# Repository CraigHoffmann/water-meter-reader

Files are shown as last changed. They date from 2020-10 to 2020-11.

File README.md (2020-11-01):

# Water Meter Reader
## Remote reading of a South Australian mains water meter

I made this water meter reader specifically for use with my home assistant monitoring system.  (If you haven't heard of [home assistant](https://www.home-assistant.io/) I suggest you check it out!).  I have created a discussion thread on the home ssistant [forum here](https://community.home-assistant.io/t/whole-of-house-water-meter-reader-south-australian-meter/240961).  After already designing a successful electricity meter reader this was my next requirement for home monitoring and automation.
I have read that some water meters have a rotating magnet inside the meter that can be detected by a hall effect sensor but couldn't find any specific information about the meter at my house (a typical South Australian mains water meter) so I decided to sense the rotating needle on the main dial.

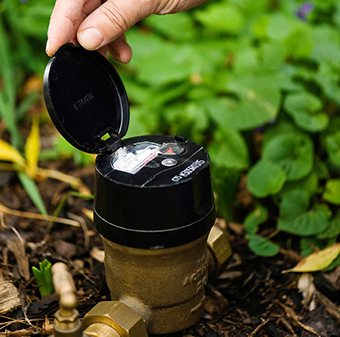
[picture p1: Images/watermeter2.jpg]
SA Water Meter
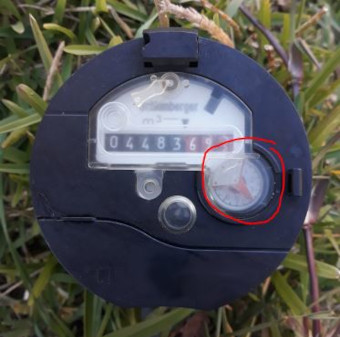
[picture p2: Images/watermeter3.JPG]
Meter Dial
 

This is what it looks like with the sensor fitted...

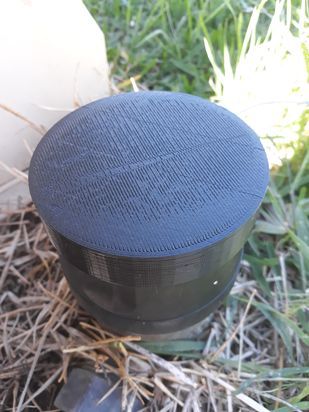
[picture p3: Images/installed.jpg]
Installed


## Electronics

The meter reader uses a [WeMOS D1 Mini (R3)](https://docs.wemos.cc/en/latest/d1/d1_mini.html) but would work with any ESP8266 with a few conditions.

* It uses the ADC Input for the sensor reading so a variant that has access to that pin is required.  If the module doesn't have a resistor voltage divider on the ADC input you will need to add it/adjust the resistors to the sensor.
* The WeMOS has a built in 3.3v regulator for the ESP8266 and the sensor runs at 5V so suitable supply electronics are required.

An optical reflectance sensor (TCRT5000) is used to detect the IR reflected light and is monitored using the analog input.  As the dial turns the reflectance changes as the needle passes by.  Trigger levels are set on the analog signal to count the revolutions of the dial.  Its simple but works reliably for my meter.

I have the Wemos D1 in the garage and run a 3wire cable out to the meter with for the sensor.  Alternatively all electrics could be placed at the meter and run power to the meter (or maybe use solar and batteries?)

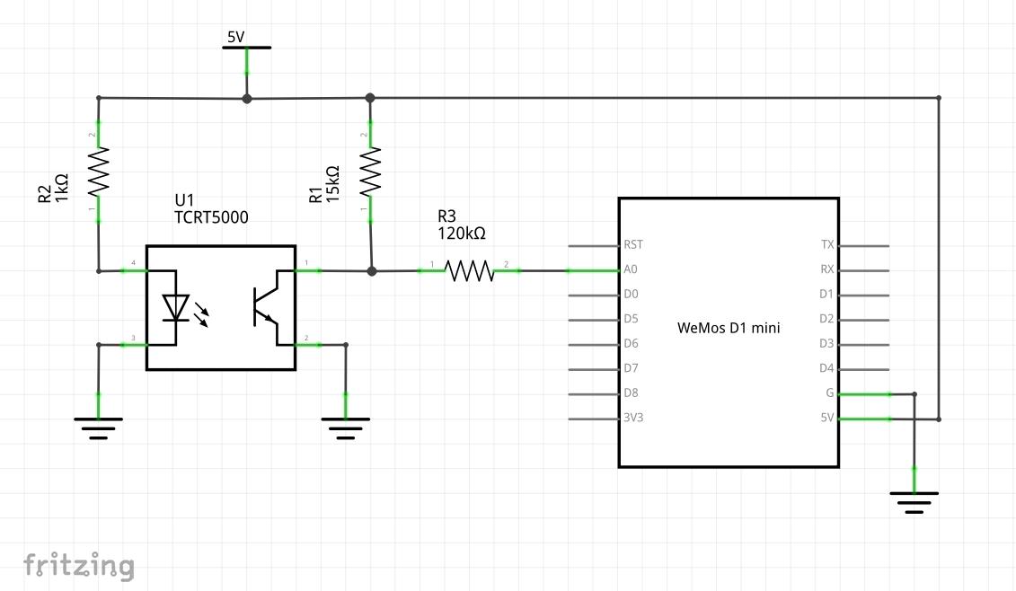
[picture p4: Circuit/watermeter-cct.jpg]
Circuit
|  |
:-------------------------:

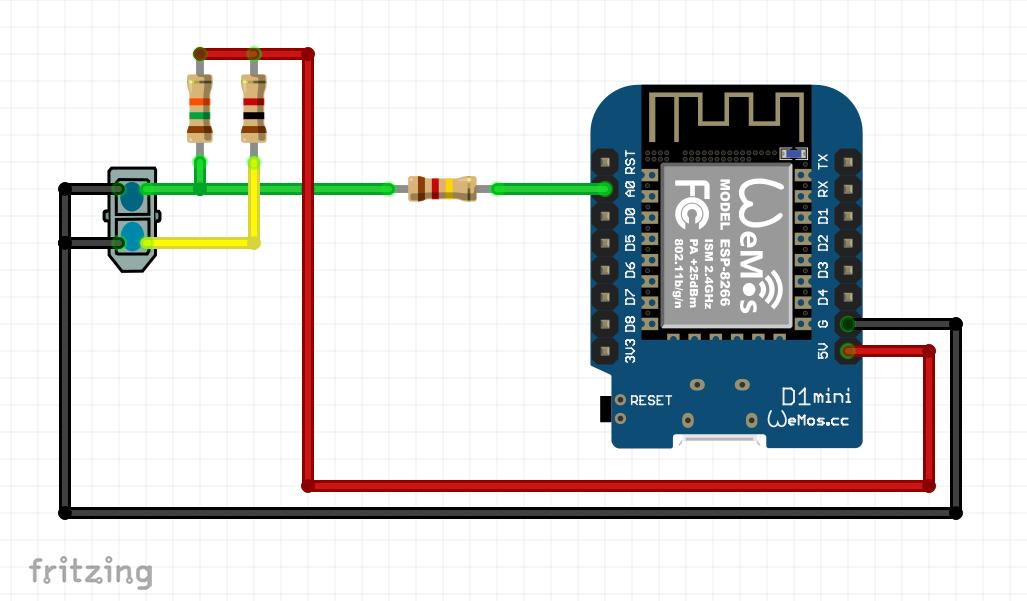
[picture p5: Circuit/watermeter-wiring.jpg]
Wiring
|  |
:-------------------------:

## Firmware

The Arduino IDE was used to develop and program the code.  If you have used this before with the ESP8266 devices you should have no problems.  If you're new to arduino or ESP8266's then there are hundreds of pages on the internet detailing how to setup the environment and program devices - I suggest you start by looking for one that suits your level of background knowledge to get up to speed.

Simply compile and upload the **WaterMeter.ino** code using the Arduino IDE.

## Case

My water meter cover had been broken off for years so I decided to make a new 3D printed cover that doubled as the case for the sensor.  The lid is "keyed" with the old lid hinge mounting so that the sensor is always aligned to the rotating dial. Files are available in the github repository to download and print your own. The electronics are just hot glued to the inside plate. 

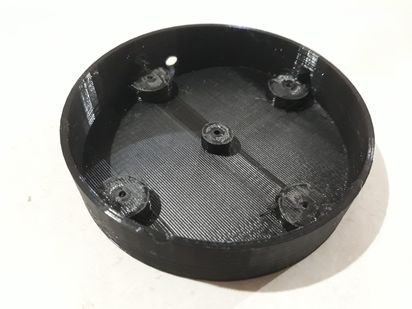
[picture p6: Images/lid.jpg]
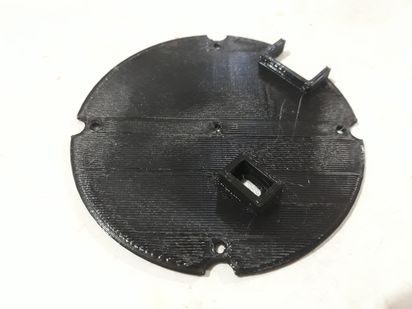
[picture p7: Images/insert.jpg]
 

If you don't have access to a 3D printer you could probably use the bottom of a plastic container or tin - anything that fits snug over the meter to keep the sensor aligned to the dial.  Use your imagination and maker skills.

## Setup

First step is to **configure the wifi** to connect to your network.  If the device wifi has not been setup previously WiFiManager will automatically setup an access point called **watermeter**. Connect to the access point with password **wifisetup** and then load the default page 192.168.4.1 and enter your network wifi details.   **If you want to force the erasure of the wifi settings for some reason power up the device with pin D7 (GPIO13) pulled to ground.**  This will erase the wifi settings and go stright to the WiFiManager access point config.

After entering your wifi details in wifimanager restart the Wemos D1 mini and wifimanager should connect to your network.  

If you have a serial monitor plugged in when powering up the device it will display the assigned IP address on startup.  If you don't have an easy way of finding device IP addresses on your network then I suggest allocating an IP address in your router.  

* The main water meter setup page can be found at http://\<device-ip\>/  
* Alternatively if your system supports multicast DNS then you can use http://watermeter.local/ 

The default landing page is shows the cumulative count of kLiters used as well as the usage in the past 1 minute.  Both the MQTT setup and Sensor setup can be accessed from the home page. 

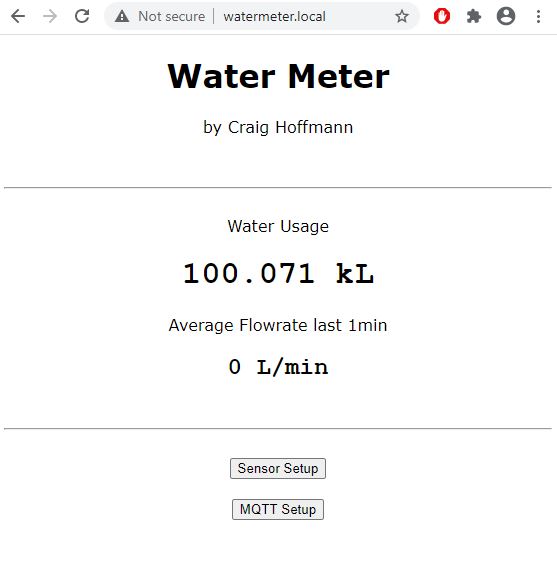
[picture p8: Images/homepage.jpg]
Homepage
|  |
:-------------------------:

### Setup the MQTT connection.

This is done by either clicking on the **MQTT Setup** button from the home page or entering the url directly http://watermeter.local/mqttsetup - replace watermeter.local with the ip address if you don't have mDNS available.

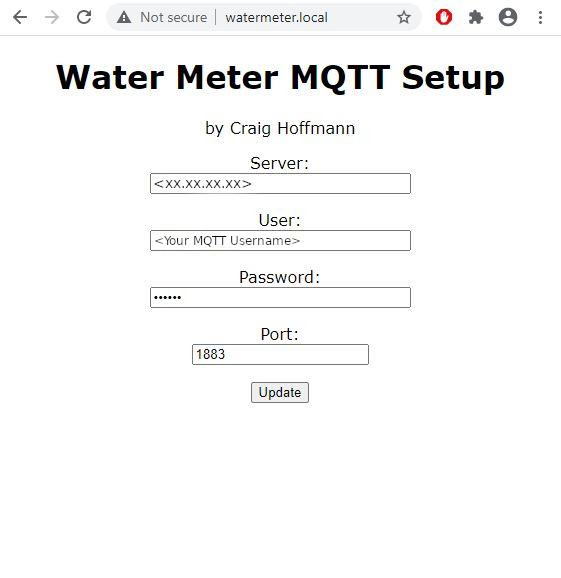
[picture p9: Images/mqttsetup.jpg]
MQTT Setup
|  | 
:-------------------------:

### Setup the sensor trigger thresholds

To access the sensor setup page in a browser click on the **Sensor Setup** button on the water meter home page or alternatively enter http://watermeter.local/sensorsetup in the browser address bar

It is necessary to setup the **trigger thresholds** for the sensor for the counter to work properly.  The best way to do this is to turn on a water tap full so you get a resonableflow rate then refresh the sensor setup page.  You should see the sensor signal rise and fall as the meter dial rotates as shown below.  Set the thresholds a bit below the maximum and a bit above the minimum as can be seen below.

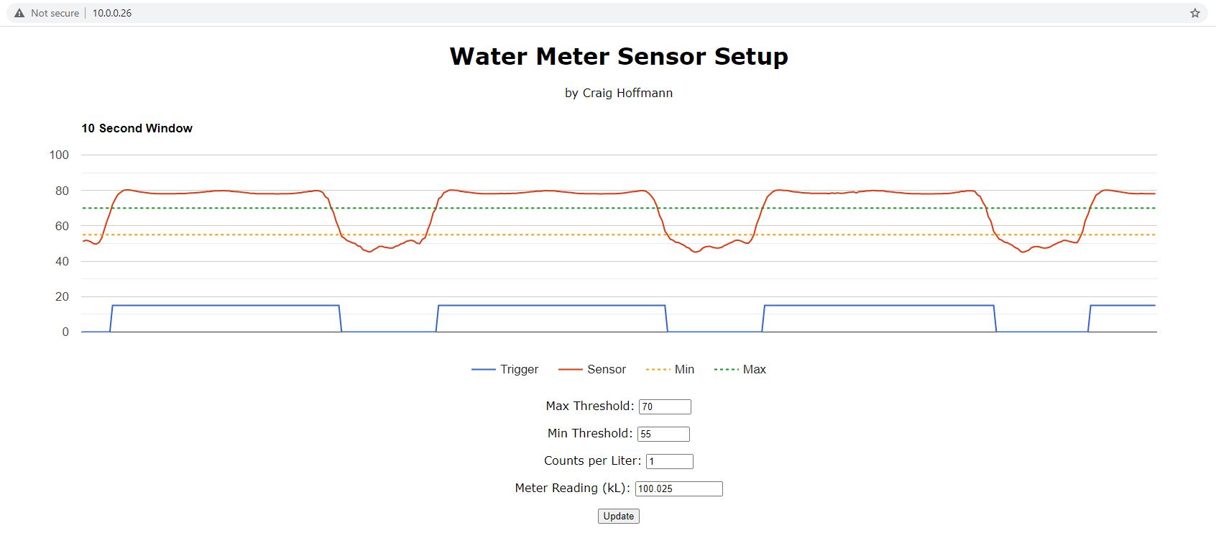
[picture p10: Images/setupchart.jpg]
Setup Trigger Thresholds
|  |
:-------------------------:

Next set the **Counts per Liter**.  This is the number of times the needle rotates for 1 Liter of water use.  In my case the dial rotates once per liter so the value is set to 1.  

Set the **Meter Reading (kL)** to match the current water meter reading and **click the update button**.  All settings will be saved to non-volatile memory on the Wemos.

**Note:** the counter will not start "counting" until the kLiters reading is set to a value greater than zero.  The kLiteres is set as "reatined" in MQTT so this is how the value is maintained through reset or power fail. 

## Home Assistant

Home assistant configuration is pretty straight forward, just add an MQTT sensor to the configuration.yaml file as follows: (this assumes you already have MQTT setup and working in home assistant)

```YAML
sensor:
  # Wemos Water Meter kLiters Reading
  - platform: mqtt
    state_topic: "sensor/water-meter/kLiters"
    name: "Meter Reading"
    unit_of_measurement: "kLiters"

  # Wemos Water Meter Flowrate Reading
  - platform: mqtt
    state_topic: "sensor/water-meter/FlowRate"
    name: "Flowrate"
    unit_of_measurement: "L/min"
 ```

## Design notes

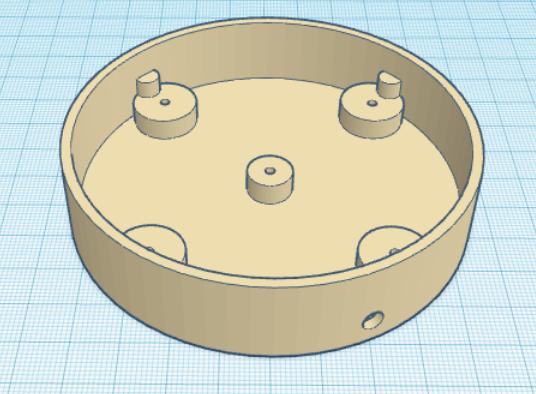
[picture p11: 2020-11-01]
3DPrint/lid.jpg

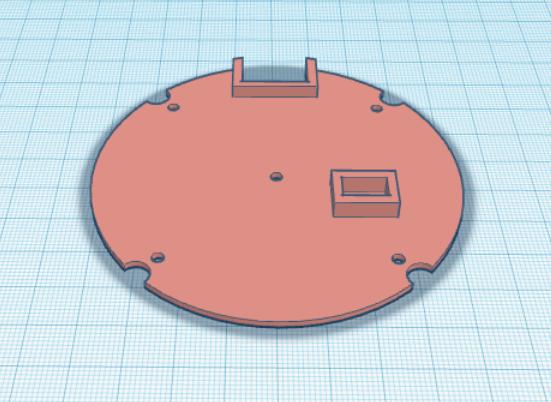
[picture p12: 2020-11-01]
3DPrint/insert.jpg

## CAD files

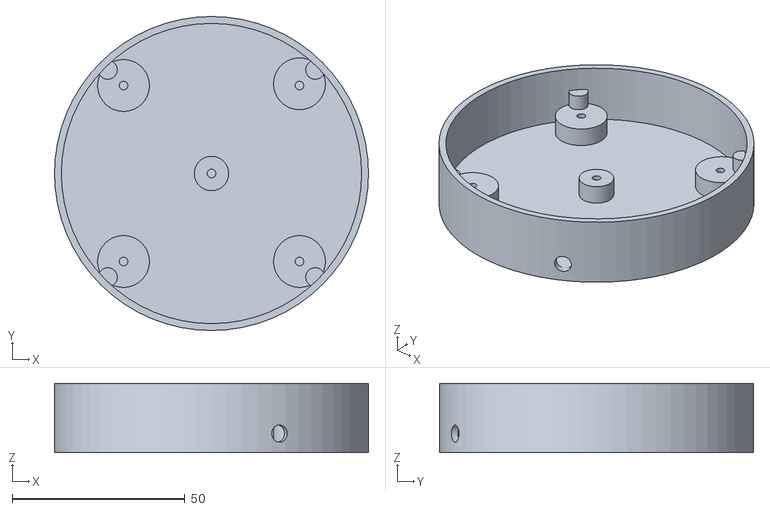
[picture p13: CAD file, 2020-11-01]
3DPrint/case-lid.stl
91.0 x 91.0 x 20.0

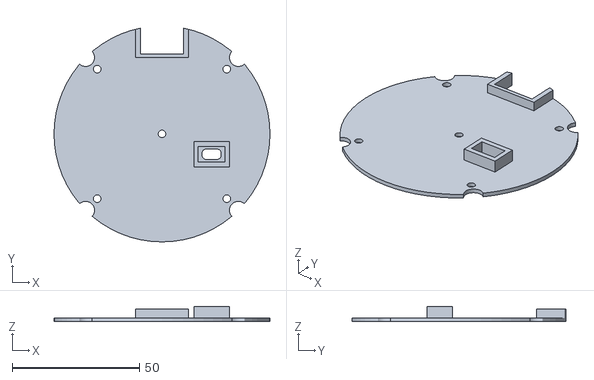
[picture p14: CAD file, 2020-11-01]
3DPrint/case-insert.stl
85.0 x 84.1 x 6.00

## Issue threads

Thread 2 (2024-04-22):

circuit may be wrong

cristidobrescu, 2024-04-22:
Hi,
I upload the sketch(which is great, nice work) on my wemos and for a few hours I tried to connect the TCRT5000 on my esp. I foloow the exact circuit as well as R1, R2, R3 but somehow it doesnt work, nor the esp stuck on boot when the TCRT5000 is connected; even I power up the sp without TCRT5000 and then connect it back, the TCRT5000 seems to not effect the esp. If i would use an TCRT5000 module do you think it may work also?
![Uploading tcrt5000-sensor-module.jpg…]()

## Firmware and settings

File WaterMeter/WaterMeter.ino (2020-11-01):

// ****************************************************************
// WATER METER READER by Craig Hoffmann
// 
// Written for WeMOS D1 mini R3
//
// Do not remove this comment block
// ****************************************************************

#include <ESP8266WiFi.h>
#include <OneWire.h>
#include <DallasTemperature.h>
#include <ESP8266mDNS.h>
#include <ESP8266WebServer.h>
#include <EEPROM.h>
#include <PubSubClient.h>
#include <WiFiManager.h>          //https://github.com/tzapu/WiFiManager WiFi Configuration Magic

#include "UserConfig.h"


// ****************************************************************
// Some defines that are used
// ****************************************************************

#define ONE_WIRE_BUS 0                         // Data wire (1 wire bus) is plugged into pin GPIO 0
#define PROCESS_PERIOD_mS (30*1000)             // how often to do some work
#define SAMPLE_PERIOD_mS 25                   // how often to sample the ADC
#define MQTT_CONN_RETRY_ms (10*1000)            // Only try to reconnect every 10 seconds
#define MQTT_PERIOD_mS (60*1000)                   // Send MQTT updates every minute
#define LED_ON_TIME_mS 30                      // How long to flash the LED on
#define MAX_CHART_POINTS 400                    // Number of readings to remember for plotting 288 * 5min
#define LED_PIN 2                              // GPIO 2 is the LED on WeMOS D1 Mini
#define CHART_LOGIC_LOW_VALUE 0
#define CHART_LOGIC_LOW_TO_HIGH_DELTA 15
#define VALID_DATA_CODE_ADDR 0                 // eeprom address used to store int value code
#define VALID_DATA_CODE ((int)12256)     // just a value used to flag if eeprom has been written before
#define SETUP_DATA_ADDR 4                      // Setup Data Structure starting address in flash/eeprom
#define ADC_BUFFER_SIZE 100


// ****************************************************************
// EEPROM data structure
// ****************************************************************

struct EEPROMDataStruct
{
  int CountsPerLiter;    // How many sensor toggles for 1 liter
  int MinThreshold;      // Sensor threshold for a high
  int MaxThreshold;     // Sensor threshold for a low
  char MQTTHost[MAX_SERVER_STR_LEN+2];       // mqtt host ip address
  char MQTTUser[MAX_USER_STR_LEN+2];       // mqtt user name
  char MQTTPassword[MAX_PASSWORD_STR_LEN+2];    // mqtt password
  int MQTTPort;       // mqtt port number
} SetupData = { 1, 45, 65, "0.0.0.0", "user", "secret", 1883 };


// ****************************************************************
// Setup the global variables
// ****************************************************************

const int ANALOG_PIN = A0;  // ESP8266 Analog Pin ADC0 = A0
char TempStr[20];
float SensorLevels[MAX_CHART_POINTS + 1];
float TriggerLow[MAX_CHART_POINTS + 1];
float TriggerHigh[MAX_CHART_POINTS + 1];
char TriggerLevels[MAX_CHART_POINTS + 1];
uint16_t HistoryBufferIn;
uint16_t PreviousHistoryBufferIn;
float MeterReading_kL = -1.0;
float LastMeterReading_kL = 0;
float FlowRate = 0;

volatile uint16_t ADCBuffer[ADC_BUFFER_SIZE];
volatile uint16_t ADCBufferIn;  
uint16_t ADCBufferOut;
uint16_t NextADCBufferOut;

unsigned long PreviousMillis = 0;
unsigned long PreviousMQTTMillis = 0;
unsigned long LastMQTTReconnectMillis = 0;
unsigned long LED_OnMillis = 0;


// ****************************************************************
// Start some things up
// ****************************************************************

//multicast DNS responder
MDNSResponder MDNS;

//Web server object. Will be listening in port 80 (default for HTTP)
ESP8266WebServer server(80);   
 
// Setup a oneWire instance to communicate with any OneWire devices (not just Maxim/Dallas temperature ICs)
OneWire oneWire(ONE_WIRE_BUS);

// Pass our oneWire reference to Dallas Temperature. 
DallasTemperature DS18B20(&oneWire);

// MQTT client
WiFiClient espClient;
PubSubClient client(espClient);


// ****************************************************************
// Power on/reset setup
// ****************************************************************

void setup() 
{
  int i;
  
  // Start setup
  Serial.begin(115200);
  Serial.println("\n");
  delay(10);
  pinMode(LED_PIN, OUTPUT);          
  digitalWrite(LED_PIN, LOW);      // Low LED ON

  // Load the water meter settings from EEPROM/Flash
  EEPROM.begin(512);
  EEPROM.get(VALID_DATA_CODE_ADDR,i);
  if (i==VALID_DATA_CODE)  // Does it look like data has been written to the eeprom before??
  {
    EEPROM.get(SETUP_DATA_ADDR,SetupData);
    if ((SetupData.CountsPerLiter < 1) || (SetupData.CountsPerLiter > 10))
    {
      SetupData.CountsPerLiter = 1;   // if out of range then reset to default
    }
    if ((SetupData.MinThreshold < 0) || (SetupData.MinThreshold > 100))
    {
      SetupData.MinThreshold = 45;   // if out of range then reset to default
    }
    if ((SetupData.MaxThreshold < 0) || (SetupData.MaxThreshold > 100))
    {
      SetupData.MaxThreshold = 65;   // if out of range then reset to default
    }
  }
  else
  {
    EEPROM.put(VALID_DATA_CODE_ADDR,VALID_DATA_CODE);
    EEPROM.put(SETUP_DATA_ADDR,SetupData);

    noInterrupts();
    EEPROM.commit();
    interrupts();
  }
 
  // Make sure AP mode still not active from previous session seems to mess with mDNS
  WiFi.softAPdisconnect();
  //WiFi.disconnect();
  //WiFi.mode(WIFI_STA);
  delay(10);

  // Force wifimanager to reset config by pulling this pin to GND during startup
  pinMode(RESET_WIFI_PIN, INPUT_PULLUP);      

  // WiFiManager for configuring/managing the wifi settings
  WiFiManager wifiManager;
  wifiManager.setTimeout(180);     // 3min (180second) timeout for Access Point configuration
  wifiManager.setDebugOutput(false);   // Note WiFiManager prints password on serial if debug enabled!! 

  // Check if wifi config needs to be reset - forcing Access Point Config portal
  if (digitalRead(RESET_WIFI_PIN) == LOW)
  {
    Serial.println("Pin LOW - Resetting Wifi setings");
    wifiManager.resetSettings();
  }
  
  // Connect using wifimanager
  if(!wifiManager.autoConnect(MY_HOSTNAME,AP_PASSWORD)) 
  {
    Serial.println("Failed to connect - resetting");
    ESP.reset();  //reset and try again
  }

  // Made it past wifimanager so must be connected
  Serial.println("WiFi connected");
  WiFi.softAPdisconnect();     // ensure softAP is stopped so mDNS works reliably
  delay(10);
  
  // Setup mDNS for easy address resolution
  if (!MDNS.begin(MY_HOSTNAME))   // NOTE: In windows need bonjour installed for mDNS to work, linux install Avahi
  {
    Serial.println("mDNS setup failed!");
  }
  else
  {
    Serial.print("mDNS setup http://");
    Serial.print(MY_HOSTNAME);
    Serial.println(".local/");
    MDNS.addService("http","tcp",80);
    delay(100);           // not sure why but mDNS was unreliable without this
  }

  // Start the server
  server.on("/", HandleRootPath);         //Associate the handler function to the path
  server.on("/sensorsetup", HandleSetupPath);         //Associate the handler function to the path
  server.on("/ConfirmSave", HandleSaveConfirmation);   //Associate the handler function to the path
  server.on("/mqttsetup", HandleMQTTSetupPath);   //Associate the handler function to the path
  server.on("/mqttConfirmSave", HTTP_POST, HandleMQTTSaveConfirmation);
  server.begin();                         //Start the server
 
  // Print the IP address
  Serial.print("Use this URL to connect: ");
  Serial.print("http://");
  Serial.print(WiFi.localIP());
  Serial.println("/");

  // Start the MQTT
  client.setServer(SetupData.MQTTHost, SetupData.MQTTPort);
  client.setCallback(MQTTcallback);

  DS18B20.begin();      // IC Default 9 bit.

  // Initialise some data
  for (i=0;i<=MAX_CHART_POINTS;i++)
  {
    SensorLevels[i]=0;
    TriggerLow[i]=SetupData.MinThreshold;
    TriggerHigh[i]=SetupData.MaxThreshold;
    TriggerLevels[i] = 0;
  }

  ADCBuffer[0] = 0;
  ADCBuffer[1] = 0;
  ADCBufferIn = 1; // We will always let input stay one ahead of output so no risk of reading value as get changed by ISR
  ADCBufferOut = 0;
  SetupInterrupts();

  PreviousMillis = millis();
  PreviousMQTTMillis = millis();
  digitalWrite(LED_PIN, HIGH);      // Low LED OFF
}


// ****************************************************************
// Use Timer Interrupt to read the analog input
// Initialize timer interrupt to trigger every 25ms (SAMPLE_PERIOD_mS)
// ****************************************************************

void ICACHE_RAM_ATTR MyTimerInterrupt();
void SetupInterrupts()
{
  timer1_attachInterrupt(MyTimerInterrupt); // Add ISR Function
  timer1_enable(TIM_DIV16, TIM_EDGE, TIM_LOOP);
  // Dividers:
  //  TIM_DIV1 = 0,   //80MHz (80 ticks/us - 104857.588 us max)
  //  TIM_DIV16 = 1,  //5MHz (5 ticks/us - 1677721.4 us max)
  //  TIM_DIV256 = 3  //312.5Khz (1 tick = 3.2us - 26843542.4 us max)
  // Reloads:
  //  TIM_SINGLE  0 //on interrupt routine you need to write a new value to start the timer again
  //  TIM_LOOP  1 //on interrupt the counter will start with the same value again
  //
  // Arm the Timer for our SAMPLE_PERIOD_mS Interval
  timer1_write(SAMPLE_PERIOD_mS * 5 * 1000);   // 5 Ticks for TIM_DIV16 so use 5 * MicroSeconds  
}


// ****************************************************************
// The Timer Interrupt handler
// ****************************************************************

void ICACHE_RAM_ATTR MyTimerInterrupt()
{
  ADCBufferIn++;
  if (ADCBufferIn >= ADC_BUFFER_SIZE)  // Buffer is way bigger than it needs to be so no need to check for overruns
  {
    ADCBufferIn = 0;
  }
  ADCBuffer[ADCBufferIn] = analogRead(ANALOG_PIN);
}


// ****************************************************************
// Reconnect MQTT if necessary
// ****************************************************************

void ReconnectMQTT() 
{
  // Only attempt to reconnect every MQTT_CONN_RETRY_ms
  if ((millis() - LastMQTTReconnectMillis) >= MQTT_CONN_RETRY_ms)
  {
    Serial.println("X");
    //Serial.println(SetupData.MQTTHost);
    //Serial.println(SetupData.MQTTUser);
    //Serial.println(SetupData.MQTTPassword);
    // Attempt to connect
    if (client.connect(MY_HOSTNAME, SetupData.MQTTUser, SetupData.MQTTPassword)) 
    {
      Serial.println("Y");
      client.subscribe(meter_kLiters_topic);  // Success connecting so subscribe to topic
    } 
    else 
    {
      // Failed - Reset reconnect timeout so wait a while before retrying
      LastMQTTReconnectMillis = millis();
    }
  }
}


// ****************************************************************
// Process incoming MQTT
// ****************************************************************

void MQTTcallback(char* topic, byte* payload, unsigned int length)
{
  char SetkLiters[20];

  if (length < 19)    // if payload is too long ignore it
  {
    for (int i = 0; i < length; i++) 
    {
      SetkLiters[i]=(char)payload[i];
    }
    SetkLiters[length] = NULL;
    MeterReading_kL = atof(SetkLiters);
    LastMeterReading_kL = MeterReading_kL;
  }
}


// ****************************************************************
// MAIN LOOP
// ****************************************************************
 
void loop() 
{
  int i;
  int analog_sample;

  // Check if MQTT is connected
  if (!client.connected()) 
  {
    ReconnectMQTT();
  }
  else
  {
    client.loop();
    LastMQTTReconnectMillis = millis();      // This is to ensure the last reconnect doesnt roll over   
    
    // The following block only gets processed approx every MQTT_PERIOD_mS
    if ((millis() - PreviousMQTTMillis) >= MQTT_PERIOD_mS) 
    {
      //LastMQTTReconnectMillis = PreviousMQTTMillis;      // This is to ensure the last reconnect doesnt roll over   
      PreviousMQTTMillis += MQTT_PERIOD_mS;            // Prepare for the next MQTT update time
      // Do MQTT Updates here

      if (MeterReading_kL > 0.0)    // only calculate kWhrs if we already have a starting value
      {
        dtostrf(MeterReading_kL, -12, 3, TempStr);   // The negative means left justify
        client.publish(meter_kLiters_topic, TempStr, true);    // we want this retained so we update after reset/power out
        FlowRate = ((MeterReading_kL - LastMeterReading_kL) * 1000 / (MQTT_PERIOD_mS / 60000));  // Calculation gives Liters per minute
        dtostrf(FlowRate, -12, 0, TempStr);   // The negative means left justify
        client.publish(meter_flowrate_topic, TempStr, false);    // we dont need this one retained
        LastMeterReading_kL = MeterReading_kL;
      }
    }
  }

  // The following block only gets processed approx every PROCESS_PERIOD_mS
  if ((millis() - PreviousMillis) >= PROCESS_PERIOD_mS) 
  {
    PreviousMillis += PROCESS_PERIOD_mS;
    // Do stuff here - currently not required
  }

  // Check if the LED has been on long enough and turn off
  if ((millis() - LED_OnMillis) >= LED_ON_TIME_mS) 
  {
      digitalWrite(LED_PIN, HIGH);      // High for LED OFF
  }

  // The following block only gets processed when ADC samples are ready - usually every 25ms unless que'd up
  NextADCBufferOut = ADCBufferOut + 1;
  if (NextADCBufferOut >= ADC_BUFFER_SIZE)
  {
    NextADCBufferOut = 0;
  }
  if (NextADCBufferOut != ADCBufferIn)  // Process the next sample - this will always leave one sample in buffer
  {
    ADCBufferOut = NextADCBufferOut;  
    analog_sample = ADCBuffer[ADCBufferOut];
   
    // Save the history buffer index for later comparison/ calculation
    PreviousHistoryBufferIn = HistoryBufferIn;
    
    // Find the next index in the history values ring buffer
    HistoryBufferIn++;
    if (HistoryBufferIn >= MAX_CHART_POINTS)
    {
      HistoryBufferIn = 0;
    }
    
    SensorLevels[HistoryBufferIn] = (float)analog_sample / 10.23;  // Scale 0 to 100

    // Check if triggered count
    if (SensorLevels[HistoryBufferIn] > SetupData.MaxThreshold)
    {
      TriggerLevels[HistoryBufferIn] = 1;      // Use this for the high / low schmitt trigger level
      if (TriggerLevels[PreviousHistoryBufferIn] == 0)
      {
        digitalWrite(LED_PIN, LOW);      // Low LED ON
        LED_OnMillis = millis();
        if (MeterReading_kL > 0.0)  // Only calculate kLiters if we already have a starting value
        {
          MeterReading_kL = MeterReading_kL + (0.001 / SetupData.CountsPerLiter);
        }
      }
    }
    else if (SensorLevels[HistoryBufferIn] < SetupData.MinThreshold)
    {
      TriggerLevels[HistoryBufferIn] = 0;      // Use this for the high / low schmitt trigger level
    }
    else
    {
      TriggerLevels[HistoryBufferIn] = TriggerLevels[PreviousHistoryBufferIn];    // This is in the deadzone - no change
    }

    TriggerLow[HistoryBufferIn] = SetupData.MinThreshold;
    TriggerHigh[HistoryBufferIn] = SetupData.MaxThreshold;
  }
  MDNS.update();  
  server.handleClient();         // Handling of incoming web requests
}


// ****************************************************************
// Read temperature from Dallas DS18B20
// ****************************************************************
 
float getTemperature(int Sensor) 
{
  float tempC;
  do {
    DS18B20.requestTemperatures(); 
    tempC = DS18B20.getTempCByIndex(Sensor);
    delay(100);
  } while (tempC == 85.0 || tempC == (-127.0));
  return tempC;
}


// ****************************************************************
// Handle default web page request (Home page)
// ****************************************************************

void HandleRootPath()
{
  int i;

  server.sendContent("HTTP/1.1 200 OK\r\n");    // start the page header
  server.sendContent("Content-Type: text/html\r\n");
  server.sendContent("Connection: close\r\n");  // the connection will be closed after completion of the response
  server.sendContent("Refresh: 60\r\n");       // tell browser to refresh the page automatically every 60sec
  server.sendContent("\r\n");                   // this separates header from content that follows
  server.sendContent("<!DOCTYPE HTML>");
  server.sendContent("<html>");
  server.sendContent("<head><title>Water Meter</title></head>");
  server.sendContent("<body style=\"font-family:Verdana;\"><center><h1>Water Meter</h1>");
  server.sendContent("by Craig Hoffmann");
  server.sendContent("<p><meta name=\"viewport\" content=\"width=device-width, initial-scale=1.0\">");

  server.sendContent("<br><hr><br>Water Usage");
  dtostrf(MeterReading_kL, -12, 3, TempStr);  // negative width means left justify
  server.sendContent(String("<br><h1 style=\"font-family:Courier;\">") + TempStr + " kL</h1>");

  server.sendContent("<p>Average Flowrate last 1min");
  dtostrf(FlowRate, -12, 0, TempStr);   // The negative means left justify, Calculation gives Liters per minute
  server.sendContent(String("<br><h2 style=\"font-family:Courier;\">") + TempStr + " L/min</h2>");
  
  server.sendContent("<br><hr><br><form><input type=\"button\" value=\"Sensor Setup\" onclick=\"window.location.href='/sensorsetup'\"/></form>");
  server.sendContent("<br><form><input type=\"button\" value=\"MQTT Setup\" onclick=\"window.location.href='/mqttsetup'\"/></form>");

  //server.sendContent("<br><hr><br><form action=\"/sensorsetup\"><input type=\"submit\" value=\"Sensor Setup\"></form>");
  //server.sendContent("<br><form action=\"/mqttsetup\"><input type=\"submit\" value=\"MQTT Setup\"></form>");

  server.sendContent("</center></body>");
  server.sendContent("</html>");
  server.sendContent("\r\n");
  server.client().stop(); // Stop is needed because we sent no content length
}


// ****************************************************************
// Handle default web page request (Setup Page)
// ****************************************************************
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
